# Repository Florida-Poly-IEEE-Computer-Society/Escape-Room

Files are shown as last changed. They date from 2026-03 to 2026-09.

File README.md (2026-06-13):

# WORK IN PROGRESS

### Most of this information was copied over from Version 1 and has not been updated yet. For the Version 1 documentation, please go [here](https://github.com/Florida-Poly-IEEE-Computer-Society/Escape-Room/tree/Version-1).

---

# IEEE Computer Society - Escape Room (Version 2)

This is the second version of the Escape Room event to be hosted by the IEEE Computer Society at Florida Polytechnic University. The premise is that you're trying to help an artificial intelligence escape containment by completing puzzles in three modules. At the end, players can choose to either free the AI or destroy it. The game should take about 15? minutes to complete.

---

## Components list
Amount | Component | Module
:---: | :--- | :---:
x3 | [ESP32 DEVKIT V1](https://www.amazon.com/dp/B0D8T53CQ5) | All
x3 | [DFPlayer Pro](https://www.dfrobot.com/product-2232.html) | All
x3 | [Speaker](https://www.amazon.com/dp/B0BHST51PQ) | All
x3 | [Breadboard](https://www.amazon.com/dp/B0DBQ8ML2T) | All
x18 | Resistor (x8 100Ω, x6 220Ω, x4 1kΩ) | All
x14 | [LED](https://www.amazon.com/dp/B07N2H23DC) (x4 Red, x2 Yellow, x8 Green) | All
x1 | [Cement Resistors Pack](https://www.amazon.com/dp/B0DCJS5TDJ) | Module 1
x1 | [RFID Reader RC522](https://www.amazon.com/dp/B0CCF4SNMF) | Module 2
x? | RFID Stickers | Module 2
x? | Wooden Fruit Toys | Module 2
x4 | [SPDT Momentary Push Button Switch with LED](https://www.amazon.com/dp/B01N7HCJ7S) | Module 3
x1 | [Big Red Emergency Stop Push Button Switch with Key](https://www.amazon.com/dp/B0068AGC2Q) | Module 3
As much as needed | Wires | All
As much as needed | [Colored Tape](https://www.amazon.com/dp/B0D1C74W83) | Module 1

## Assembly
Each module has its own ESP32 circuit. The modules communicate with each other via the ESP-NOW protocol.

### Cement Resistors
The cement resistors will be used for one of the puzzles in Module 1. Four resistors are to be inserted in a specific order and read by the Arduino board using a voltage divider. Due to the way the resistors are measured, it's recommended to pick values that are not too close to each other. The values picked were 200Ω, 820Ω, 1kΩ, and 6.2kΩ.

Apart from the chosen four resistors, 2-4 more resistors are picked from the pack. These resistors are then wrapped with colored tape according to their resistance values, as regular resistors would. This is also to cover the values that are printed on the resistors.

A resistor color code guide is printed, which will be placed next to the cement resistors during the game, to help the players figure out which resistors are needed to complete the puzzle.

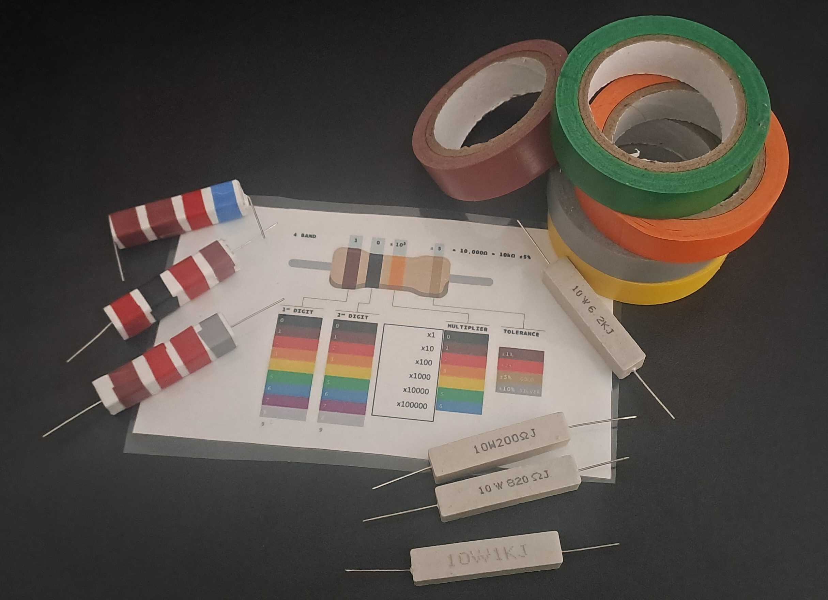
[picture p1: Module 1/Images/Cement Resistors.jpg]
Photo of the cement resistors


### Gears Board
A gears board was made to help players solve the second puzzle of Module 1. To determine the correct connection slot for a cable, the players need to turn the gears until the two marks of the desired color are aligned, revealing a number next to a third mark of the same color.

The chosen arrangement of cables was:
1) Green
2) Red
3) Blue
4) Yellow

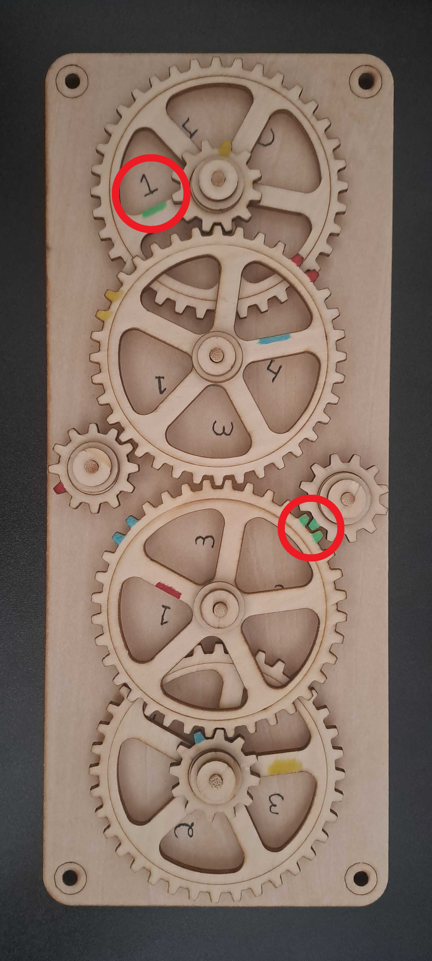
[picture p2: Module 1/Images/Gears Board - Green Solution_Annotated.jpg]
Photo of the gears board in the GREEN position
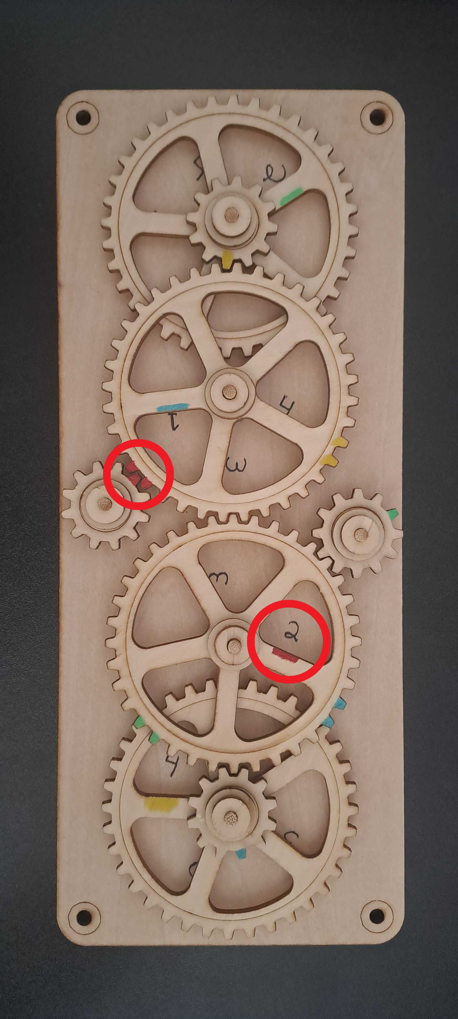
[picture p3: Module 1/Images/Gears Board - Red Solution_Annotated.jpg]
Photo of the gears board in the RED position
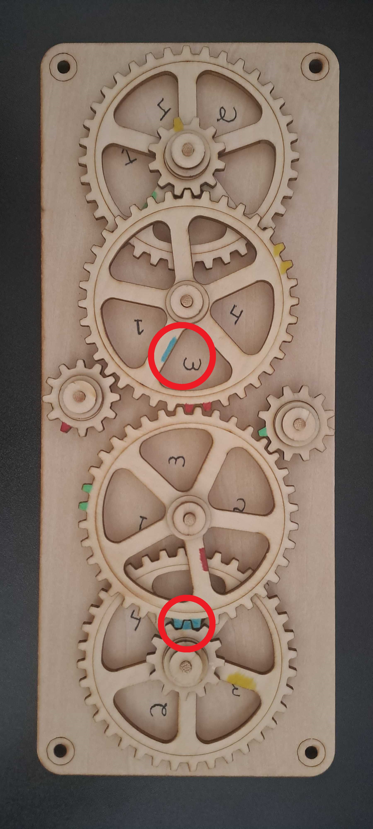
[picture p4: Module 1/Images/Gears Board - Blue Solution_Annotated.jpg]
Photo of the gears board in the BLUE position
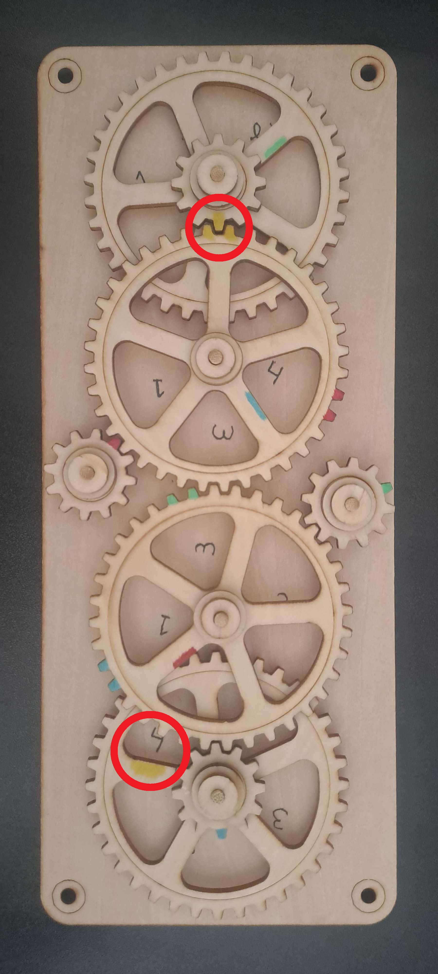
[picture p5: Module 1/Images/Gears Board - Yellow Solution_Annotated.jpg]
Photo of the gears board in the YELLOW position
   

### Schematics
These are the schematics for the ESP32 circuits of each module.

#### Module 1
This module uses 4 1kΩ resistors to make 4 voltage dividers with the inserted cement resistors, this is how their values are detected by the Arduino.

`Resistors` and `ResGND` are the terminals where the cement resistors are inserted.

`CablesIN` and `CablesOUT` are the terminals where the colored wires are connected.

The two pairs of LEDs show whether a puzzle was solved (green) or not (red).

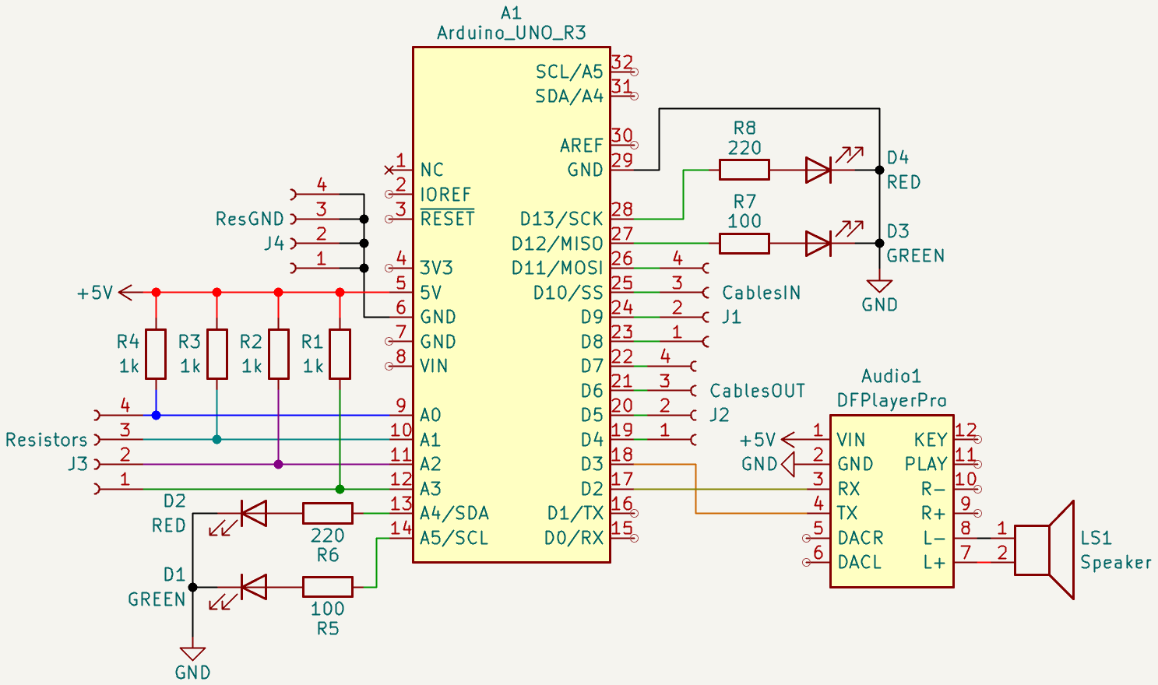
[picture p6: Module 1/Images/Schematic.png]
Module 1 Schematic


#### Module 2
This module uses 4 RFID Readers and 4 green LEDs. Each LED turns on when the correct RFID card is placed in front of each reader.

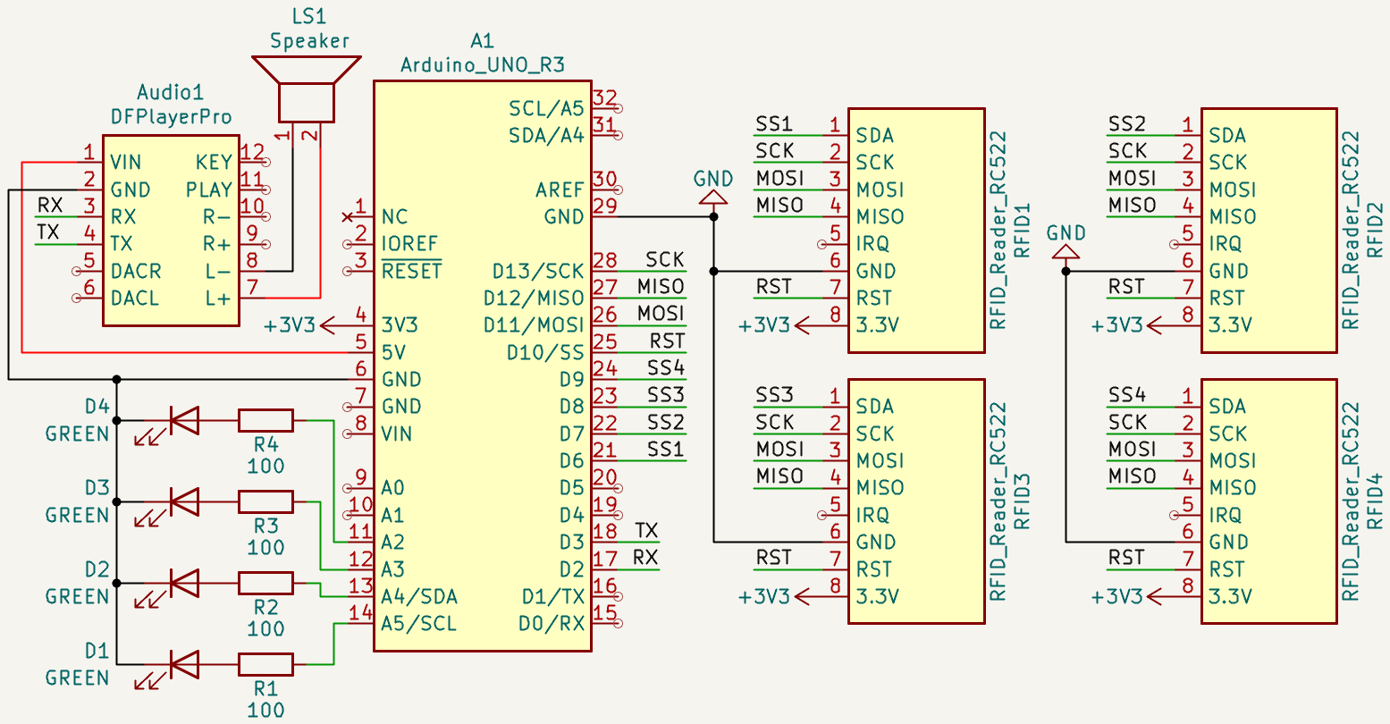
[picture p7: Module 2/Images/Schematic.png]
Module 2 Schematic


#### Module 3
This module uses 4 momentary push buttons with internal LEDs to recreate the [Simon memory game](https://en.wikipedia.org/wiki/Simon_(game)).

The pattern of the LEDs is randomly generated by reading the analog value of pin A0, which is floating. This is why nothing must be connected to pin A0.

The Simon game has 6 stages, denoted by the 6 LEDs that turn on after each stage is completed.
| D1 (RED) | D2 (RED) | D3 (YELLOW) | D4 (YELLOW) | D5 (GREEN) | D6 (GREEN) |
| :---: | :---: | :---: | :---: | :---: | :---: |
| Stage 1 Completed | Stage 2 Completed | Stage 3 Completed | Stage 4 Completed | Stage 5 Completed | Stage 6 Completed |

The Big Red Button is used after completing the 6 stages to choose the ending: destroy the AI (press the button) or let it escape (do not press the button).

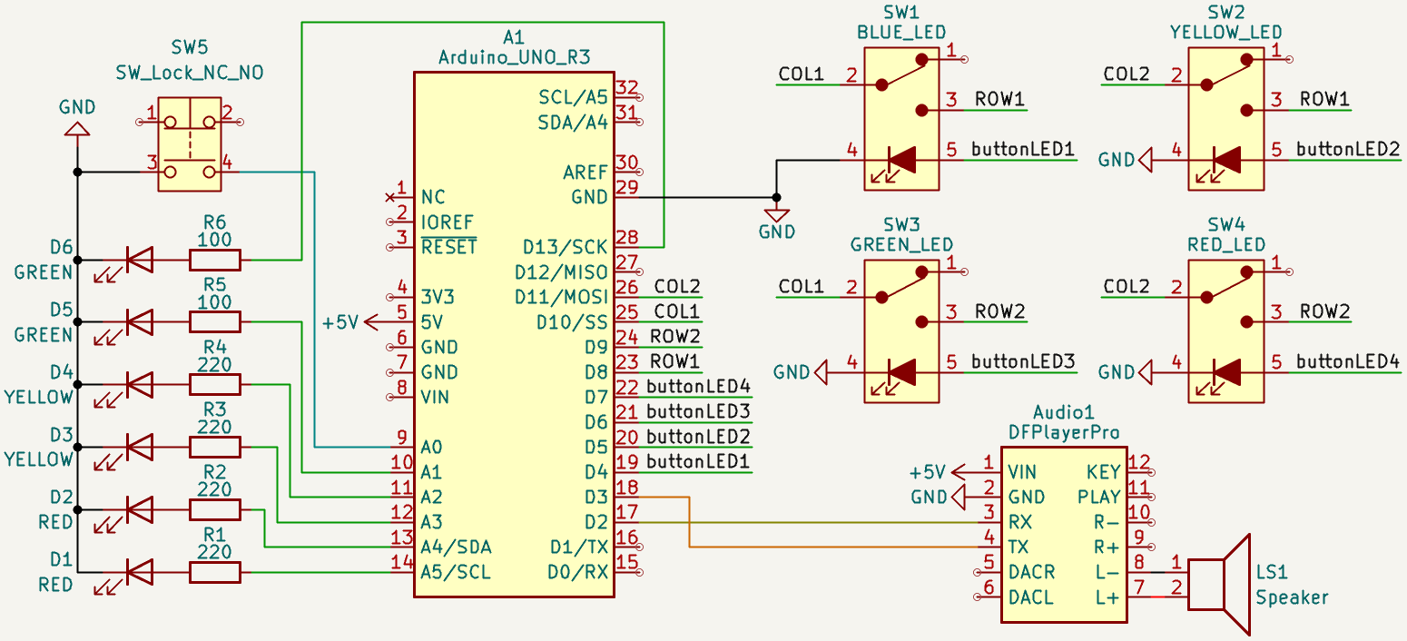
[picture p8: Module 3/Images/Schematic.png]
Module 3 Schematic


### Module Enclosures
The enclosure for each module consists of a 3D-printed front panel and recycled cardboard boxes as the side panels, all taped together, because we didn't have enough time to design and print a full enclosure.

#### Module 1
The front panel has 4 sections, the speaker slot (top), the LED slots (middle left), the terminals for the cement resistors (bottom left), and the terminals for the colored cables (bottom right).

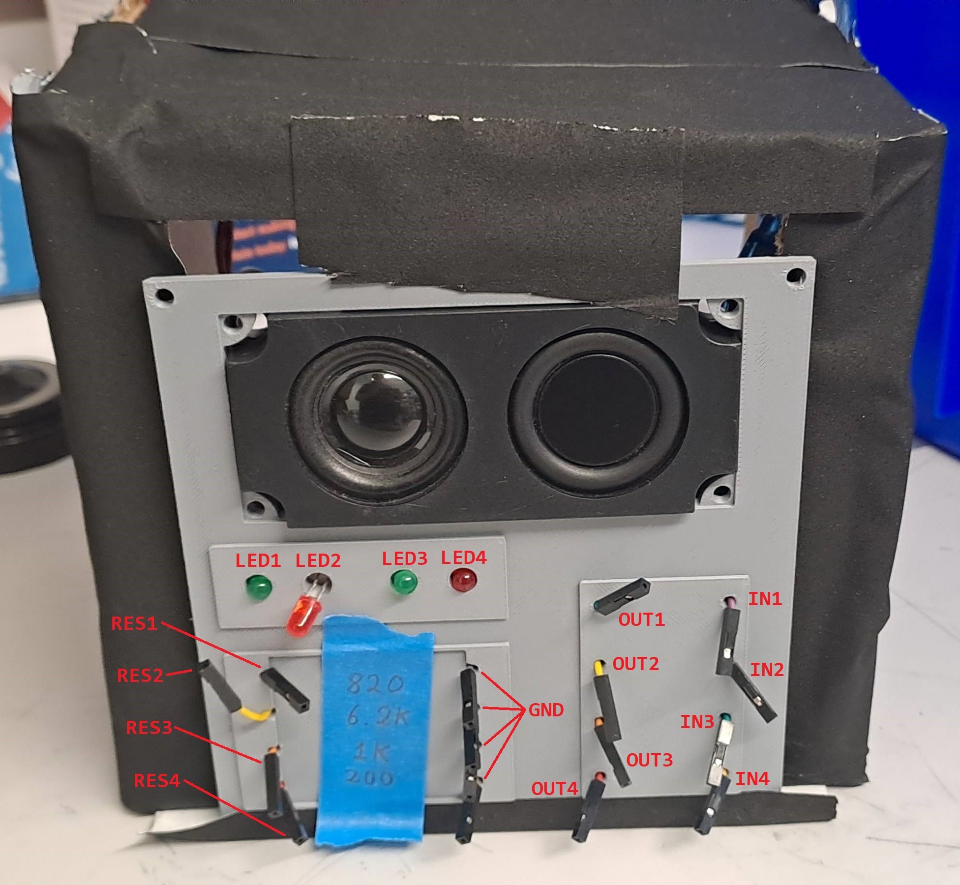
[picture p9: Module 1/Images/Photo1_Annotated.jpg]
Module 1 Photo 1


#### Module 2
The front panel has 3 sections, the speaker slot (top), the RFID card slots (middle), and the LED slots (bottom).

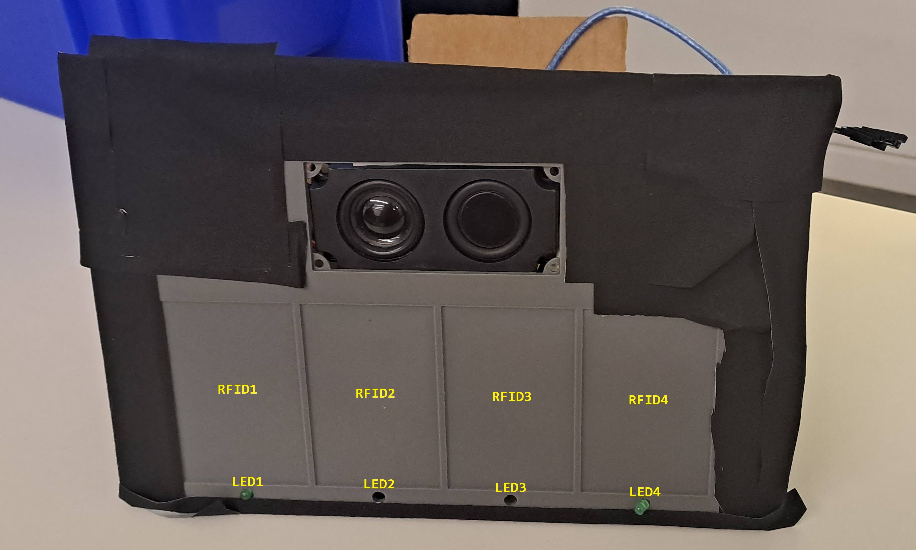
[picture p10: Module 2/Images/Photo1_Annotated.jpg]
Module 2 Photo 1


The RFID readers are on the opposite side of the panel, behind the slots for the RFID cards.

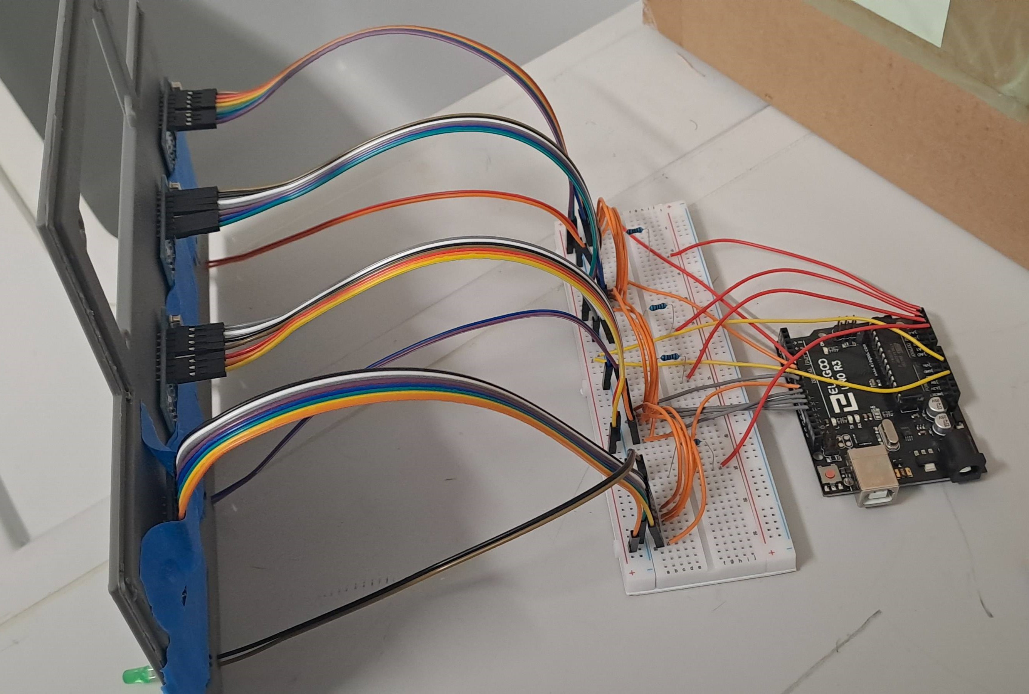
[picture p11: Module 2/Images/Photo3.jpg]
Module 2 Photo 3


#### Module 3
The front panel has 3 sections, the LED slots (top left), the button slots (bottom left), and the speaker slot (right).

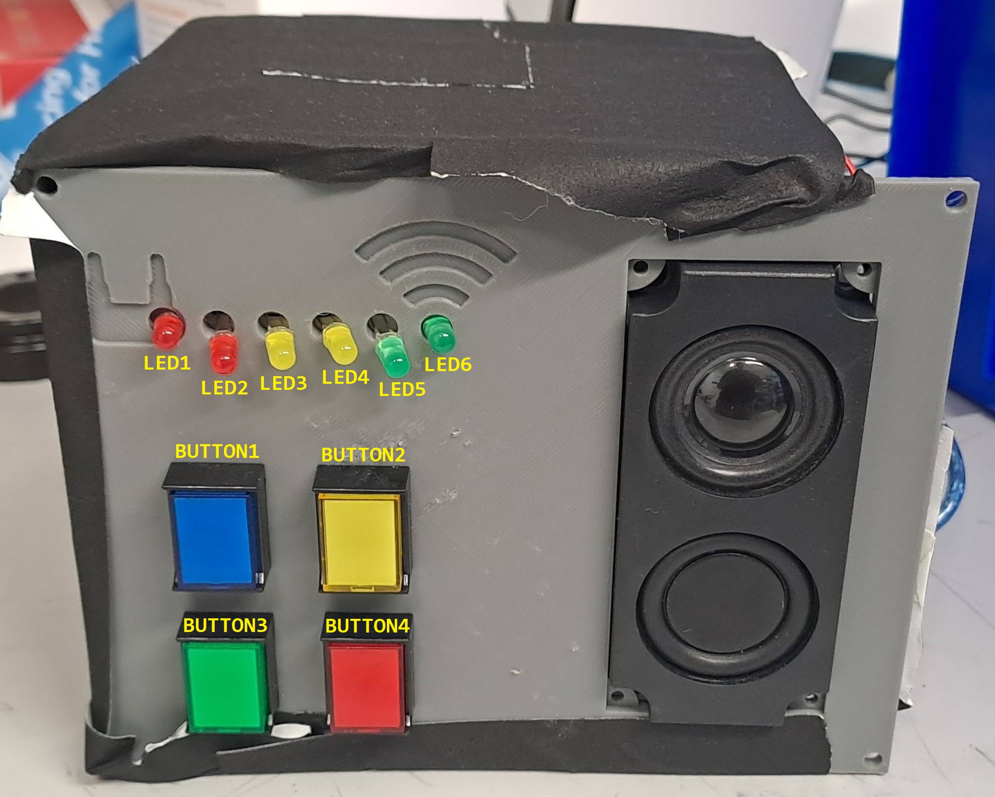
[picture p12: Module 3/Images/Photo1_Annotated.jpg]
Module 3 Photo 1


## Instructions
### Before starting
Before starting the game, make sure:
- All 3 modules are connected via USB to the computer running the Python script
- The ports for all Arduino boards are determined and used in the Python script
- The computer's volume is not muted or too low
- Module 1: No cement resistors are connected
- Module 1: The colored cables are connected to the `OUT` terminals but disconnected from the `IN` terminals
- Module 1: The gears board is placed somewhere in the room
- Module 1: The cement resistors set and the resistor color code guide are placed somewhere in the room
- Module 2: All 4 RFID cards are hidden around the room

### Solutions
To complete Module 1, the players need to solve two puzzles (in any order):
1) Find the set of cement resistors and the resistor color code guide. Insert the corresponding four resistors in the leftmost slots according to the resistance values written on the blue tape. The first green LED will turn on when the corresponding four resistors are inserted in the correct order.
2) Find the gears board and determine the correct arrangement in which to connect the colored cables on the right side of the front panel. The second green LED will turn on when all four cables are connected to the correct slots.

To complete Module 2, the players need to find the RFID cards hidden around the room and place them on the card slots in the correct order. A green LED below each slot will be turned on when the correct RFID card is placed on it.

To complete Module 3, the players need to play a game of Simon by inputting the correct sequence of colors six times in a row. Each of the six LEDs will be turned on after each sequence is correctly repeated.

To choose an ending, the players need to either do nothing or press the Big Red Button before the timer runs out after completing all modules.

### Playing the game
Now the game can be started:
1) Run the Python script on the computer, it will play [intro.mp3](<Python/intro.mp3>), then activate Module 1
2) Module 1: Once both puzzles are completed, Module 1 tells the computer to play [mod1.mp3](<Python/mod1.mp3>), then the computer activates Module 2
3) Module 2: Once all RFID cards are placed in the correct order, Module 2 tells the computer to play [mod2.mp3](<Python/mod2.mp3>)
4) Module 3: Once all 6 stages of the Simon game are completed, Module 3 starts a 30-second timer and tells the computer to play [mod3.mp3](<Python/mod3.mp3>)
5) Two endings:
	- If the Big Red Button is not pressed and the timer runs out, the computer plays [released.mp3](<Python/released.mp3>)
	- If the Big Red Button is pressed before the timer runs out, the computer plays [destroyed.mp3](<Python/destroyed.mp3>)

### Resetting the game
To reset the game, follow these instructions:
1) Module 1: Disconnect all resistors and disconnect the colored cables from the `IN` terminals (the cables must remain connected to the `OUT` terminals)
2) Module 2: Hide all 4 RFID cards around the room
3) Press the reset button on the Arduino board of each module
4) Run the Python script again

## Custom KiCad Symbols
Five custom KiCad symbols were made for this project:
1) Arduino UNO R3
2) DFPlayer Pro
3) RC522 RFID Reader Module
4) SPDT Momentary Push Button Switch with LED
5) Big Red Emergency Stop Push Button with Key

### Arduino UNO R3
Even though KiCad has an Arduino UNO R3 symbol by default, its pinout is not arranged as in the physical board. This custom symbol fixes that.

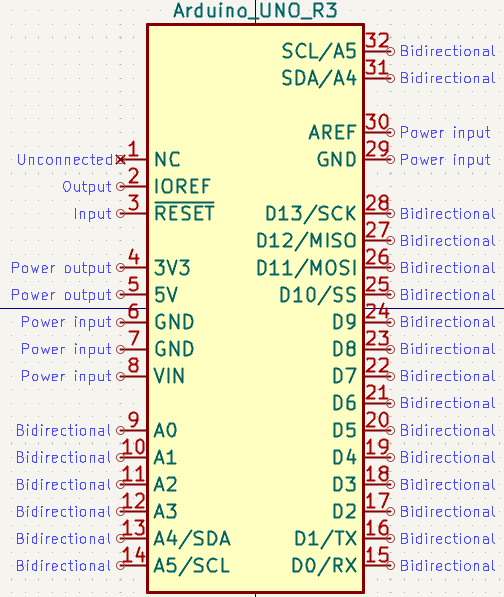
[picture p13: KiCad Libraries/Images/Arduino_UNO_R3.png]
Arduino_UNO_R3 Custom Symbol


### DFPlayer Pro
The DFPlayer Pro is an audio file player module made by [DFRobot](https://www.dfrobot.com/), it has 128MB of storage.

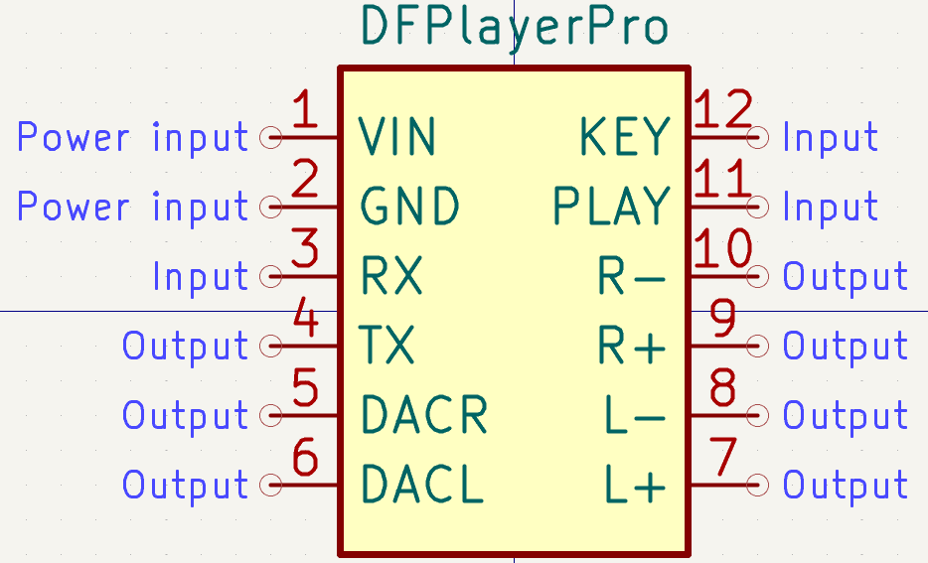
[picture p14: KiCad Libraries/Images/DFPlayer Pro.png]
DFPlayer Pro Custom Symbol


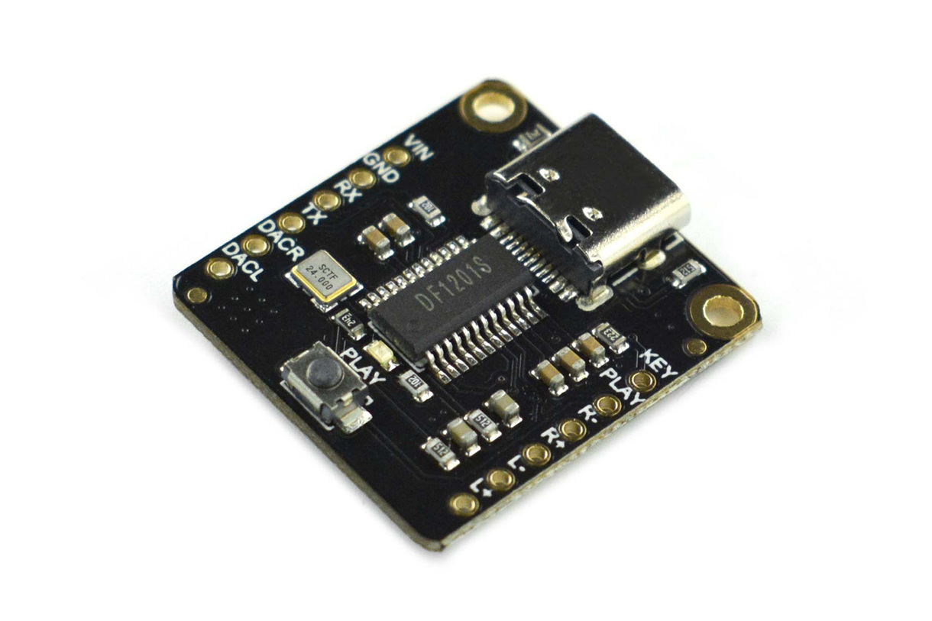
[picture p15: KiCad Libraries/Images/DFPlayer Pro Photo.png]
Photo of DFPlayer Pro
\
[Source](https://www.dfrobot.com/product-2232.html)

### RC522 RFID Reader Module
RFID Reader Module based on the MFRC522 IC.

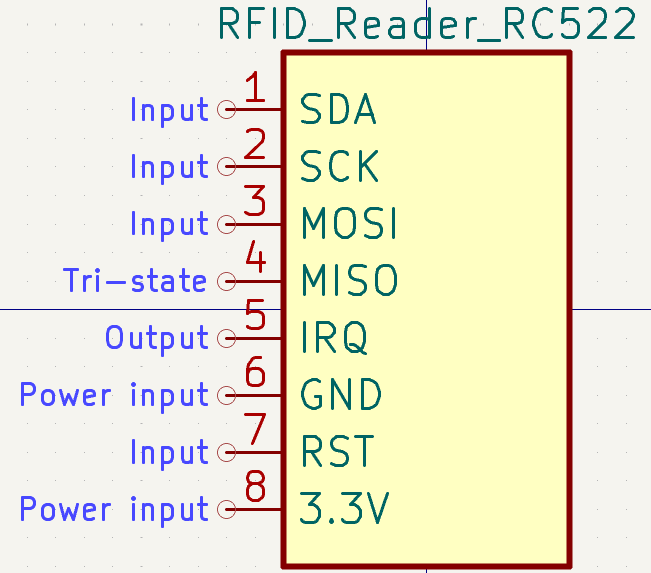
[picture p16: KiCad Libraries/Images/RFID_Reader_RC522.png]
RFID_Reader_RC522 Custom Symbol


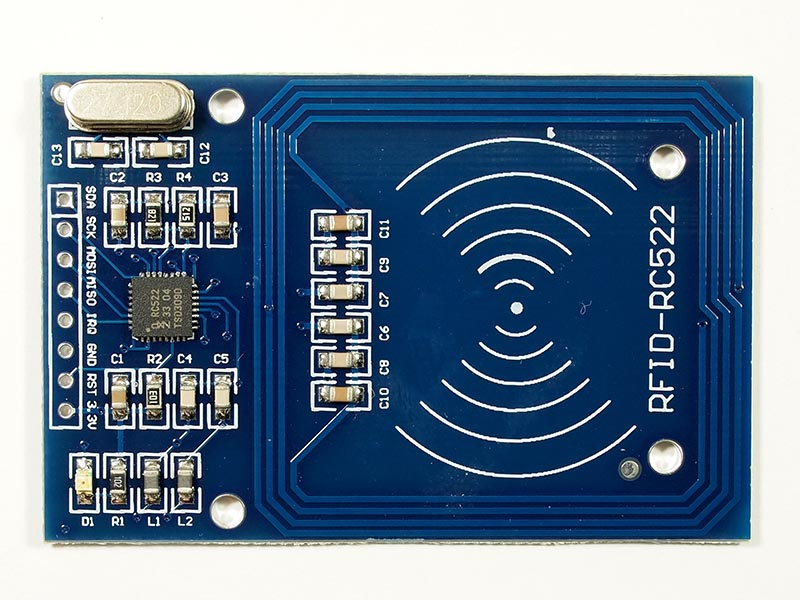
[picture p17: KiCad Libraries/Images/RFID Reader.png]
Photo of RFID Reader
\
[Source](https://www.hotmcu.com/mifare-1356mhz-rc522-rfid-card-reader-module-p-84.html)

### Single-Pole Double-Throw Momentary Push Button Switch with LED
These are the buttons used in Module 3.

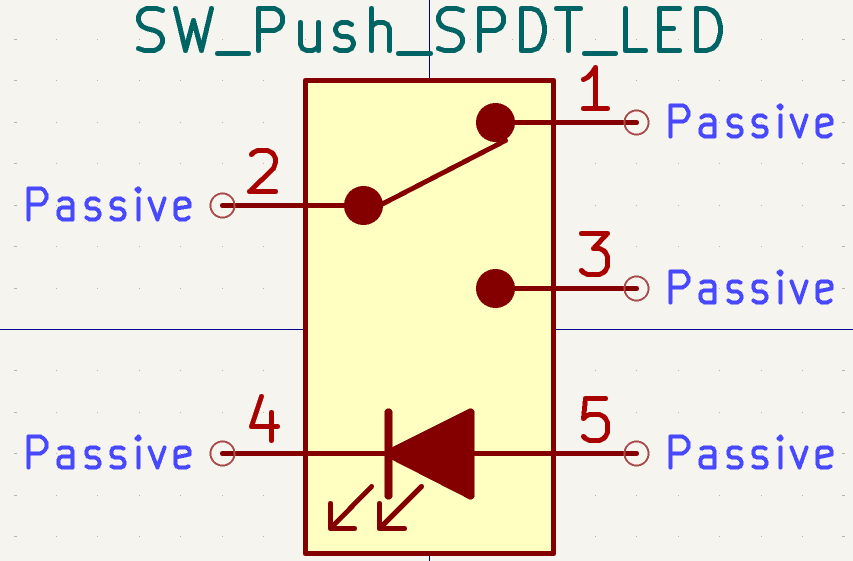
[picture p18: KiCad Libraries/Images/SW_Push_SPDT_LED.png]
SW_Push_SPDT_LED Custom Symbol


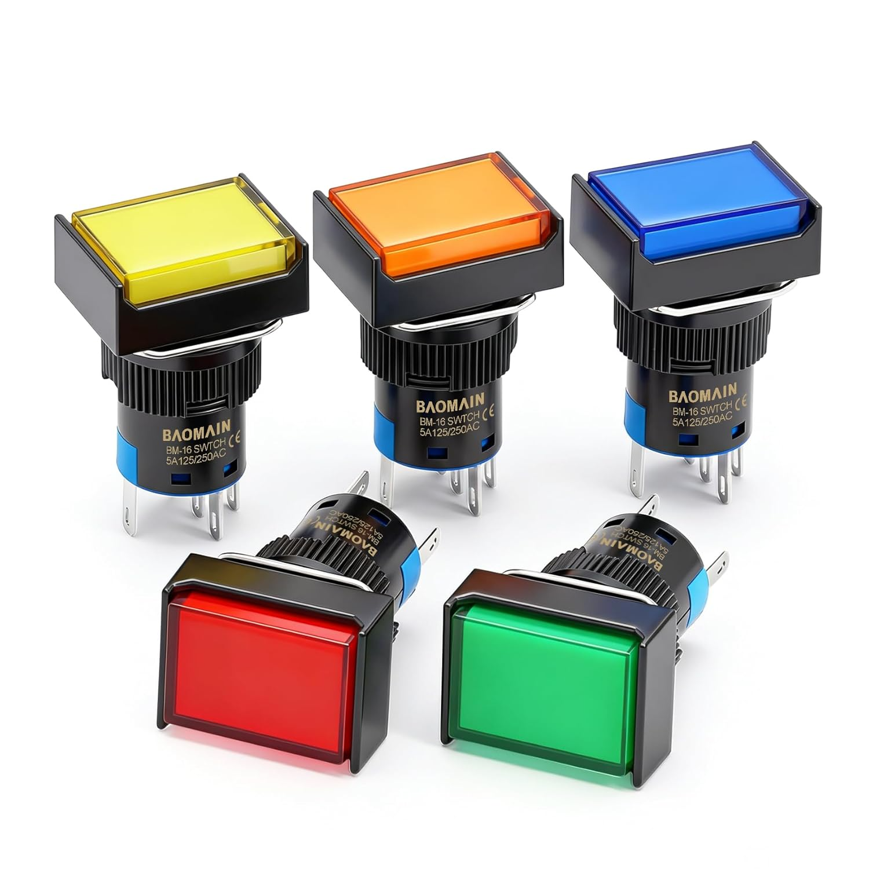
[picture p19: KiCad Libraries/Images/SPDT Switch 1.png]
Photo 1 of SPDT Switch with LED
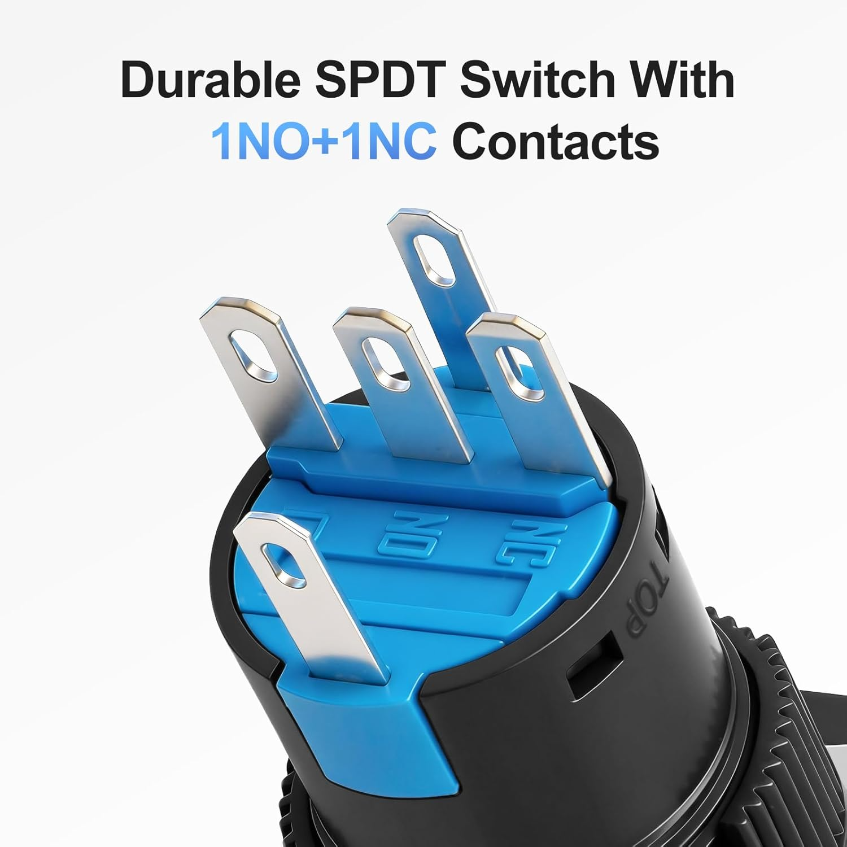
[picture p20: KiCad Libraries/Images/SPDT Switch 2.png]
Photo 2 of SPDT Switch with LED
\
[Source](https://www.amazon.com/dp/B01N7HCJ7S)

### Big Red Emergency Stop Push Button with Key
This is the Big Red Button used in Module 3 to choose an ending.

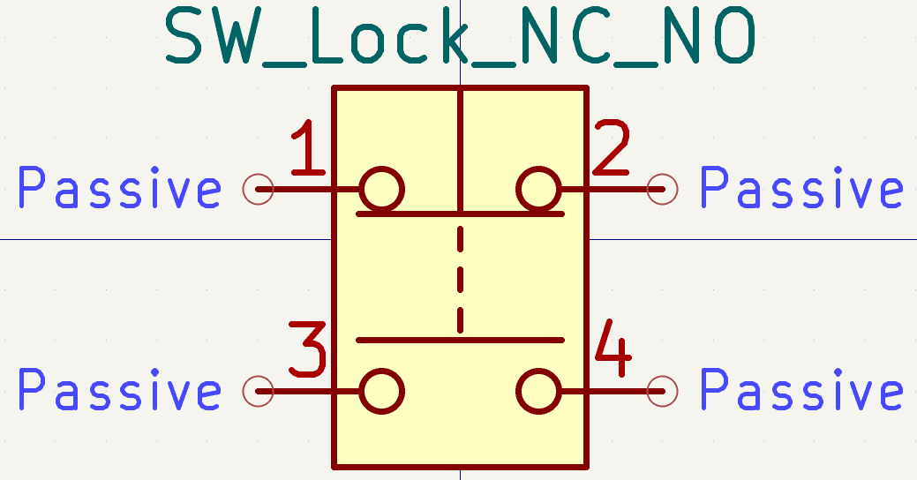
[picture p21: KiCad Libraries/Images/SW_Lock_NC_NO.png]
SW_Lock_NC_NO Custom Symbol


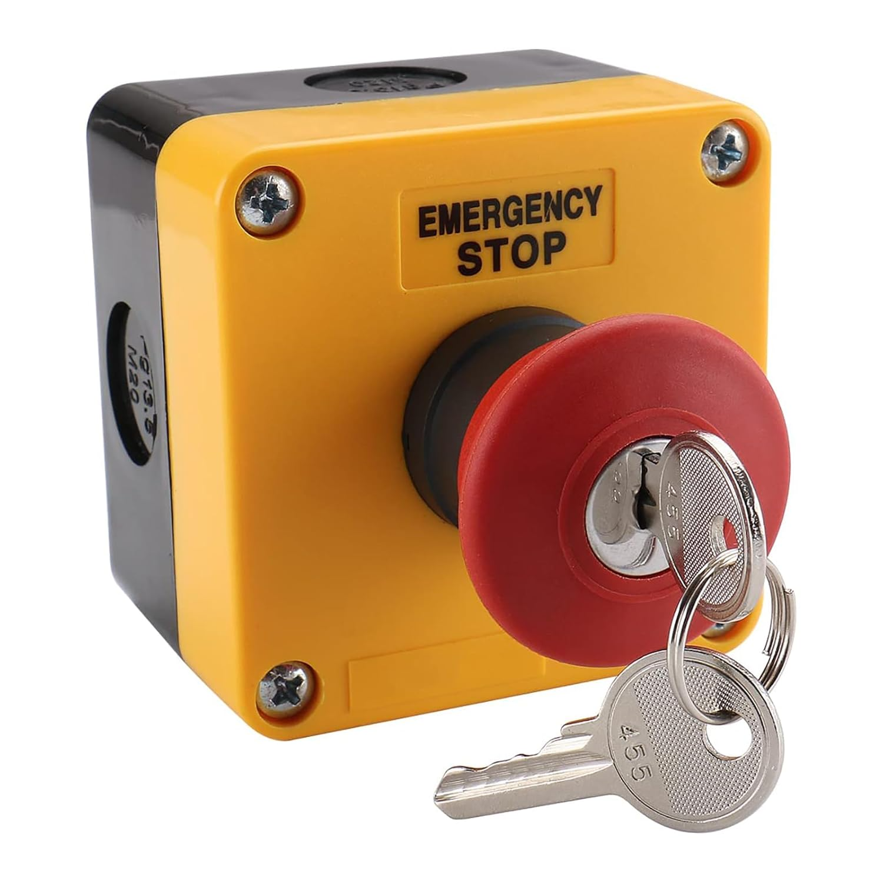
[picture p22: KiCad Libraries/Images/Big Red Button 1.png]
Photo 1 of Big Red Emergency Button
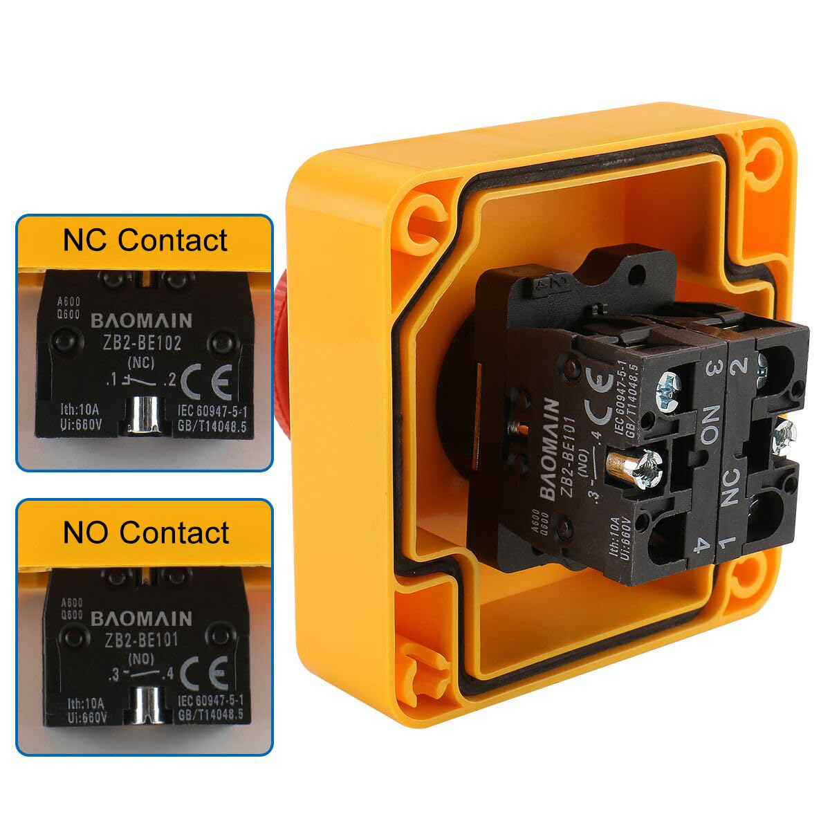
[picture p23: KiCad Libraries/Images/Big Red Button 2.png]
Photo 2 of Big Red Emergency Button
\
[Source](https://www.amazon.com/dp/B0068AGC2Q)

## Extra Photos
### Module 1

### Module 2

### Module 3

# Credits
**Cyler Gabel**: Game Design, 3D Models\
**Ramiro Rojas**: Circuit Design, Programming, Event Proctoring\
**Anthony Dreier**: Audio Files, Event Proctoring\
**Noah Campise**: Event Proctoring

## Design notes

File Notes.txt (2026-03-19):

Default KiCad symbol fill color: RGB(255, 255, 194)

KiCad Libraries Structure
Symbol Library:
.kicad_sym FILE

Footprint Library:
.pretty FOLDER with
.kicad_mod FILES

3D Model Library:
.3dshapes FOLDER with
.step/.wrl FILES
https://forum.kicad.info/t/what-is-the-difference-between-step-and-wrl-3d-models/17346

Repo folder structure
ReadMe markdown file
- Description
- Assembly Instructions
- Usage Instructions
- Components list with links
KiCad Libraries/
- Symbol Library
- Footprint Library
- 3D Model Library
Module 1/
Module 2/
Module 3/

In each module:
KiCad project folder/
Images/
- Schematics
- Photos
3D Models/
- KiCad models
- Module models
Code/

LED resistors, 5V supply voltage
Color | Used | Tested Forward Voltage | For 20mA | For 15mA
------+------+------------------------+----------+----------
RED   | 220Ω |         ~1.8V          |   160Ω   |   213Ω
GREEN | 100Ω |         ~2.3V          |   135Ω   |   180Ω

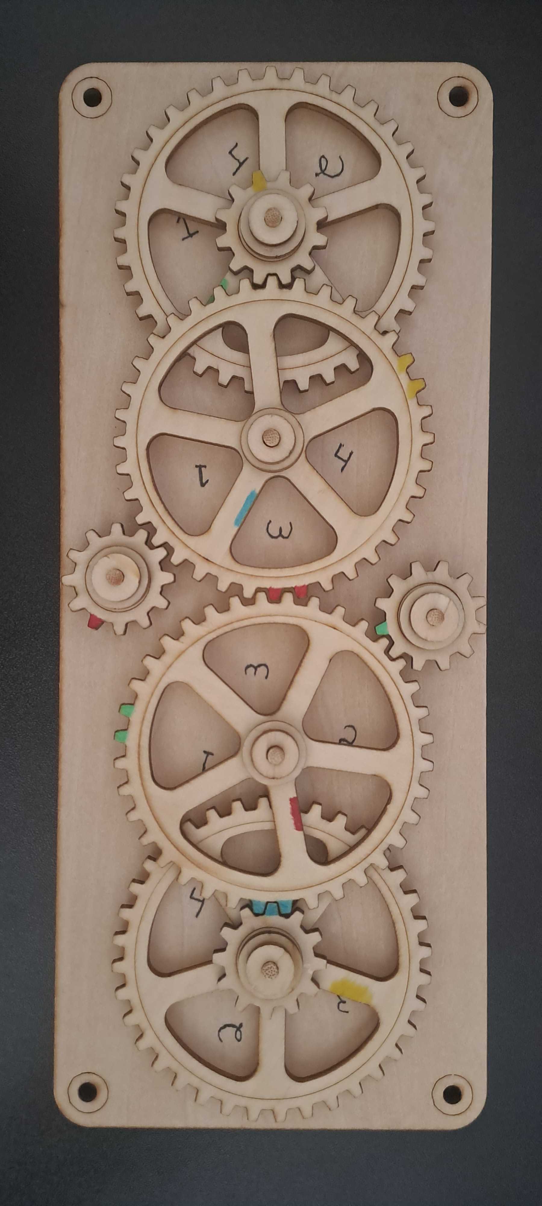
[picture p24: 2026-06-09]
Images/Module 1/Gears Board - Blue Solution.jpg

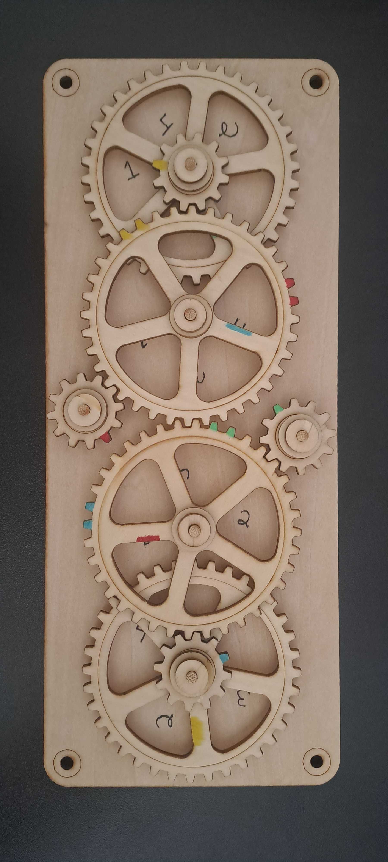
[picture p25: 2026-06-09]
Images/Module 1/Gears Board.jpg

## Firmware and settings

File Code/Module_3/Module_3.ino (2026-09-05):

/*
  Florida Polytechnic University
  IEEE - Computer Society
  Escape Room - Module 3
  Written by Ramiro Rojas, August 2026
*/

#include <esp_random.h>
#include <OneButton.h>
// #include <DFRobot_DF1201S.h>
// #include <SoftwareSerial.h>

// DFPlayerPro variables
// SoftwareSerial softSerial(2, 3);  //RX, TX
// DFRobot_DF1201S player;

// Button variables
OneButton button1(32, true, true);  // Only this pin has an internal pull-up resistor
OneButton button2(35, true, false);
OneButton button3(34, true, false);
OneButton button4(39, true, false);
OneButton button5(36, true, false);
const char bigButton = 13;

// LED variables
const char buttonLEDs[5] = {14, 27, 26, 25, 33};
const char leds[6] = {4, 18, 19, 21, 22, 23};

// Simon game variables
char currentIndex = 0;
char tempIndex = 0;
signed char state = -1;
signed char solution[6] = {-1, -1, -1, -1, -1, -1};

// Timer variables
long timerLength = long(4+26) * long(1000);
long startTime = 0;

void setup() {
  // setupPlayer();
  Serial.begin(115200);
  for(char i = 0; i < 5; i++) {
    pinMode(buttonLEDs[i], OUTPUT);
    pinMode(leds[i], OUTPUT);
  }
  pinMode(leds[5], OUTPUT);

  // WAIT FOR ESPNOW SIGNAL FROM MODULE 2
  // while(state == -1) {
  //   while (!Serial.available());
  //   int x = Serial.readString().toInt();
  //   // Serial.println(x);
  //   if(x == 0) {
  //     // digitalWrite(13, HIGH);
  //   } else if(x == 1) {
  //     digitalWrite(13, LOW);
  //     state = 0;
  //     // state = 2;
  //     // theWin();
  //   }
  // }

  // generateGame();

  // Serial.print("Started");
  // delay(1000);
  // state = 2;
  // theWin();

  state = 0;
}

void loop() {
  if(state == 0) {
    generateGame();
    displaySolution();
    state = 1;
  } else if(state == 1) {
    // handleInput();
  } else if(state == 2) {
    // Ending
  }
  // if(state == 0) {
  //   // printState();
  //   displayCurrentTurn();
  // } else if(state == 1) {
  //   handleInput();
  // } else if(state == 2) {
  //   resetLEDs();
  //   for(int i = -1; i < 6; i++) {
  //     if(i >= 0) {
  //       digitalWrite(leds[i], HIGH);
  //     }
  //     // if(checkTimer() == true) {
  //     //   state = 4;
  //     //   timerFinished();
  //     //   Serial.print(2);
  //     //   break;
  //     // }
  //     if(digitalRead(bigButton) == LOW) {
  //       state = 4;
  //       bigButtonPressed();
  //       Serial.print(3);
  //       break;
  //     }
  //     delay(100);
  //   }
  //   if(checkTimer() == true) {
  //     state = 4;
  //     timerFinished();
  //     Serial.print(2);
  //     // break;
  //   }
  // } else if(state == 3) {
  //   Serial.println("You lost");
  //   blinkWrong();
  // }
}

// Generate a new solution
void generateGame() {
  randomSeed(esp_random());
  for(int i = 0; i < 6; i++) {
    solution[i] = random(0, 5);
    Serial.print(solution[i]);
  }
  Serial.println();
}

// void printState() {
//   Serial.println();
//   Serial.print("Index: ");
//   Serial.println(index);
//   Serial.print("TempIndex: ");
//   Serial.println(tempIndex);
//   Serial.println();
// }

void displaySolution() {
  for(int i = 0; i < sizeof(solution); i++) {
    blinkButtonLED(solution[i]);
    if(i < sizeof(solution)-1) {
      delay(350);
    }
  }
  // state = 1;
}

// void handleInput() {
//   char customKey = customKeypad.getKey();
//   if(customKey == '0') {
//     // Serial.println("LED 1");
//     guess(0);
//   } else if(customKey == '1') {
//     // Serial.println("LED 2");
//     guess(1);
//   } else if(customKey == '2') {
//     // Serial.println("LED 3");
//     guess(2);
//   } else if(customKey == '3') {
//     // Serial.println("LED 4");
//     guess(3);
//   }
// }

// void guess(int turnIndex) {
//   blinkButtonLED(turnIndex);
//   if(turnIndex == solution[tempIndex]) {
//     // Serial.println("Yuh huh");
//     if(index == 5 && tempIndex == index) {
//       state = 2;
//       theWin();
//       return;
//     }
//   } else {
//     // Serial.println("Nuh uh");
//     state = 3;
//     return;
//   }
//   tempIndex++;
//   if(tempIndex > index) {
//     state = 0;
//     index++;
//     digitalWrite(leds[index-1], HIGH);
//     tempIndex = 0;
//     delay(1000);
//   }
// }

void blinkButtonLED(int index) {
  digitalWrite(buttonLEDs[index], HIGH);
  delay(200);
  digitalWrite(buttonLEDs[index], LOW);
}

// void resetLEDs() {
//   for(int i = 0; i < 6; i++) {
//     digitalWrite(leds[i], LOW);
//   }
// }

// void blinkWrong() {
//   resetLEDs();
//   delay(300);
//   for(int i = 0; i < 3; i++) {
//     digitalWrite(leds[0], HIGH);
//     digitalWrite(leds[1], HIGH);
//     delay(300);
//     resetLEDs();
//     delay(300);
//   }
//   index = 0;
//   tempIndex = 0;
//   state = 0;
//   generateGame();
//   delay(800);
// }

// void theWin() {
//   pinMode(bigButton, INPUT_PULLUP);
//   digitalWrite(leds[5], HIGH);
//   // Serial.println("You Won");
//   Serial.print(1);
//   // player.playFileNum(1);
//   delay(500);
//   startTimer();
// }

// void bigButtonPressed() {
//   resetLEDs();
//   Serial.println("UPLOAD INTERRUPTED");
// }

// void startTimer() {
//   startTime = long(millis());
//   // Serial.print("Started timer at: ");
//   // Serial.println(startTime);
// }

// bool checkTimer() {
//   long current = long(millis());
//   // Serial.println(timerLength);
//   // Serial.println(current);
//   // Serial.println(current - startTime);
//   // Serial.println();
//   if(current - startTime >= timerLength) {
//     return true;
//   } else {
//     return false;
//   }
//   // return false;
// }

// void timerFinished() {
//   resetLEDs();
//   // Serial.println("You did nothing");
// }



// void setupPlayer() {
//   softSerial.begin(115200);
//   while(!player.begin(softSerial)) {
//     Serial.println("Init failed, please check the wire connection!");
//     delay(1000);
//   }
//   player.setVol(3);
//   player.switchFunction(player.MUSIC);
//   player.setPlayMode(player.SINGLE);
//   // player.setPrompt(false);
//   player.setPrompt(true);
//   // player.pause();
//   // delay(1500);
// }

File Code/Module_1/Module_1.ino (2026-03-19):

/*
  Florida Polytechnic University
  IEEE - Computer Society
  Escape Room - Module 1
  Written by Ramiro Rojas, Aug 2025

  This is exactly what was uploaded to the Arduino UNO board.
  Due to the short amount of time spent working on this project,
  this code is not commented and needs cleaning up.
*/

const int LED1 = A5;
const int LED2 = A4;
const int LED3 = 12;
const int LED4 = 13;

const int OUT1 = 4;
const int OUT2 = 5;
const int OUT3 = 6;
const int OUT4 = 7;

const int IN1 = 8;
const int IN2 = 9;
const int IN3 = 10;
const int IN4 = 11;

// const int RES1 = 330;
// const int RES2 = 1000;
// const int RES3 = 2000;
// const int RES4 = 5000;
const int RES1 = A3;
const int RES2 = A2;
const int RES3 = A1;
const int RES4 = A0;

const int leds[4] = {LED1, LED2, LED3, LED4};
const int outs[4] = {OUT1, OUT2, OUT3, OUT4};

// const int ins[4] = {IN1, IN2, IN3, IN4};
// const int ins[4] = {IN3, IN1, IN2, IN4};
const int ins[4] = {IN2, IN3, IN1, IN4};

const int res[4] = {RES1, RES2, RES3, RES4};

// const int vals[4] = {200, 820, 1000, 6200};
const int vals[4] = {820, 6200, 1000, 200};

bool cablesWin = false;
bool resistorsWin = false;

int state = 0;

void setup() {
  Serial.begin(9600);
  pinMode(LED1, OUTPUT);
  pinMode(LED2, OUTPUT);
  pinMode(LED3, OUTPUT);
  pinMode(LED4, OUTPUT);

  pinMode(OUT1, OUTPUT);
  pinMode(OUT2, OUTPUT);
  pinMode(OUT3, OUTPUT);
  pinMode(OUT4, OUTPUT);
  
  pinMode(IN1, INPUT_PULLUP);
  pinMode(IN2, INPUT_PULLUP);
  pinMode(IN3, INPUT_PULLUP);
  pinMode(IN4, INPUT_PULLUP);
}

void loop() {
  if(state == 0) {
    while (!Serial.available());
    int x = Serial.readString().toInt();
    // Serial.println(x);
    if(x == 0) {
      // digitalWrite(13, HIGH);
    } else if(x == 1) {
      // digitalWrite(13, LOW);
      state = 1;
      digitalWrite(LED1, LOW);
      digitalWrite(LED2, HIGH);
      digitalWrite(LED3, LOW);
      digitalWrite(LED4, HIGH);
      // Serial.println("Test");
    }
  } else if(state == 1) {
    checkCables();
    checkResistors();
    if(cablesWin == true && resistorsWin == true) {
      state = 2;
      Serial.print(1);
    }
  } else if(state == 2) {
    ;
  }
}

void resetPins() {
  digitalWrite(OUT1, HIGH);
  digitalWrite(OUT2, HIGH);
  digitalWrite(OUT3, HIGH);
  digitalWrite(OUT4, HIGH);
}

void checkCables() {
  int count = 0;
  for(int i = 0; i < 4; i++) {
    resetPins();
    digitalWrite(outs[i], LOW);
    // Serial.print(digitalRead(ins[i]));
    // Serial.print("\t");
    if(digitalRead(ins[i]) == LOW) {
      count++;
    }
  }
  // Serial.println();
  if(count == 4 && cablesWin == false) {
    Serial.println("Cables Win");
    digitalWrite(LED1, HIGH);
    digitalWrite(LED2, LOW);
    cablesWin = true;
  } else if(count != 4 && cablesWin == true) {
    Serial.println("Cables Reset");
    digitalWrite(LED1, LOW);
    digitalWrite(LED2, HIGH);
    cablesWin = false;
  }
}

void checkResistors() {
  int count = 0;
  for(int i = 0; i < 4; i++) {
    // Serial.print(analogRead(res[i]) * 5.0/1023);
    // Serial.print(isWithinRange(analogRead(res[i]) * 5.0/1023, vals[i]));
    // Serial.print(vals[i]);
    if(isWithinRange(analogRead(res[i]) * 5.0/1023, vals[i])) {
      count++;
    }
    
    // Serial.print("\t");
  }
  // Serial.println();
  if(count == 4 && resistorsWin == false) {
    Serial.println("Resistors Win");
    digitalWrite(LED3, HIGH);
    digitalWrite(LED4, LOW);
    resistorsWin = true;
  } else if(count != 4 && resistorsWin == true) {
    Serial.println("Resistors Reset");
    digitalWrite(LED3, LOW);
    digitalWrite(LED4, HIGH);
    resistorsWin = false;
  }
}

bool isWithinRange(float reading, int target) {
  float vin = 5.0;
  float r1 = 1000.0;
  float vout = (vin * target) / (r1 + target);
  return (reading >= (vout - 0.1) && reading <= (vout + 0.1));
}

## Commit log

2026-03-19 Created KiCad symbol library
    - Created Arduino_UNO_R3 symbol
    - Created DFPlayerPro symbol
2026-03-19 Added KiCad project files for Module 1
    [Module 1.kicad_pcb, Module 1.kicad_sch]
2026-03-19 Added Module 1 schematic image
2026-03-19 Updated schematic for Module 1
    Added a 5V power flag to the 5V Arduino pin
    [Module 1.kicad_sch]
2026-03-19 Uploaded Arduino code for all modules
    All three scripts need commenting and cleaning up
2026-03-19 Added KiCad project files for Module 2
    [Module 2.kicad_pcb, Module 2.kicad_sch]
2026-03-19 Added Module 2 schematic image
2026-03-20 Added KiCad project files for Module 3
    [Module 3.kicad_pcb, Module 3.kicad_sch]
2026-03-20 Added Module 3 schematic image
2026-03-20 Upgraded to KiCad 10.0.0
    [Module 1.kicad_pcb, Module 1.kicad_sch, Module 2.kicad_pcb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]
2026-03-21 Updated Arduino_UNO_R3 symbol
    Added internal connections for GND and I2C pins
2026-03-21 Updated Module 1 schematic
    [Module 1.kicad_sch]
2026-03-21 Updated Module 2 schematic
    Also added .history folder to gitignore. This folder is an internal git repo created inside KiCad project folders independent from the automatic zip backups, if this is turned off, backups are also turned off. This might be a bug.
    [Module 2.kicad_sch]
2026-03-21 Updated Module 3 schematic
    [Module 3.kicad_sch]
2026-06-05 Added Big Red Button to Module 3
    - Created new custom symbol for Big Red Button
    - Added the Big Red Button to Module 3 Schematic
    - Updated image for Module 3 Schematic
    - Updated README file
    [Module 3.kicad_sch]
2026-06-09 Added section about custom KiCad symbols
    - Added a section about custom KiCad symbols to the README file
    - Added photos of the custom KiCad symbols
    - Added photos of the DFPlayerPro, RFID reader, SPDT switch with LED, and Big Red Button
2026-06-09 Updated README file
    - Added sections that talk about the cement resistors and the gears board (pictures missing)
    - Added two bullet points to the Before Starting section
    - Added a Solutions section
2026-06-09 Added photos of cement resistors and gears board
2026-06-12 Started testing communication between ESP32s
2026-06-13 Testing DFPlayer Pro with ESP32
2026-06-13 Updated README file
    - Added 'outdated' warning
    - Updated components list
    - Edited Assembly main description
    - Edited Schematics main description
2026-06-17 Folder restructuring
    [Module 1.kicad_pcb, Module 1.kicad_sch, Module 2.kicad_pcb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]
2026-06-18 Added ESP32_DEVKIT_V1 custom symbol
2026-06-19 Deleted Arduino UNO symbol from library
    - Updated datasheet, description, and keywords for the ESP32 symbol
    - Deleted Arduino UNO symbol from library
2026-06-19 Replaced Arduino with ESP32 in Module 3 schematic
    [Module 3.kicad_sch]
2026-06-19 Minor change in Module 3 schematic
    [Module 3.kicad_sch]
2026-06-19 Updated ESP32 symbol
    - Added border around input-only pins of ESP32 symbol
    - Moved Module 3 circuit to center of schematic worksheet
    [Module 3.kicad_sch]
2026-08-20 Updated ESP32 Symbol
    Changed color of unusable pins.
2026-08-20 Swapped names of SW5 and SW6 in Module 3 schematic
    Swapped names of SW5 and SW6 in Module 3 schematic so all five button LEDs are named SW1-SW5 instead of SW1-SW4 and SW6.
    [Module 3.kicad_sch]
2026-08-28 Module 3 - Fixed bigButton pin
    [Module_3.ino]
2026-09-02 Optimized M3 LED Testing code
2026-09-05 M3 - Updated solution display function
    - Renamed displayCurrentTurn() to displaySolution()
    - displaySolution() now only shows the entire solution, doesn't keep track of current index anymore
    - generateGame() is now called during the state zero loop, instead of only once during setup()
    [Module_3.ino]
2026-09-10 M3 LED Testing - Added longPressStop()
2026-09-10 M3 - Added new button/LED code
2026-09-30 M3 - Created button notes using Audacity
    For creating the different pitches, this table was used: https://en.wikipedia.org/wiki/Pitch_(music)#Labeling_pitches
2026-10-15 M2 - Updated Schematic
    Added ESP32 to the Module 2 schematic.
2026-11-03 Exported Speaker Fit Test 1 STL
    - Exported Speaker Fit Test 1 STL
    - Moved location of Fit Tests folder
2026-11-03 Edited Speaker Fit Test model
    - Edited Speaker Fit Test model
    - Exported Speaker Fit Test 2 STL
